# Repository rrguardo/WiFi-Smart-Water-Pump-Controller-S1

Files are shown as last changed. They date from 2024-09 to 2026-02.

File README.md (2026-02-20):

# WiFi Smart Water Pump Controller S1

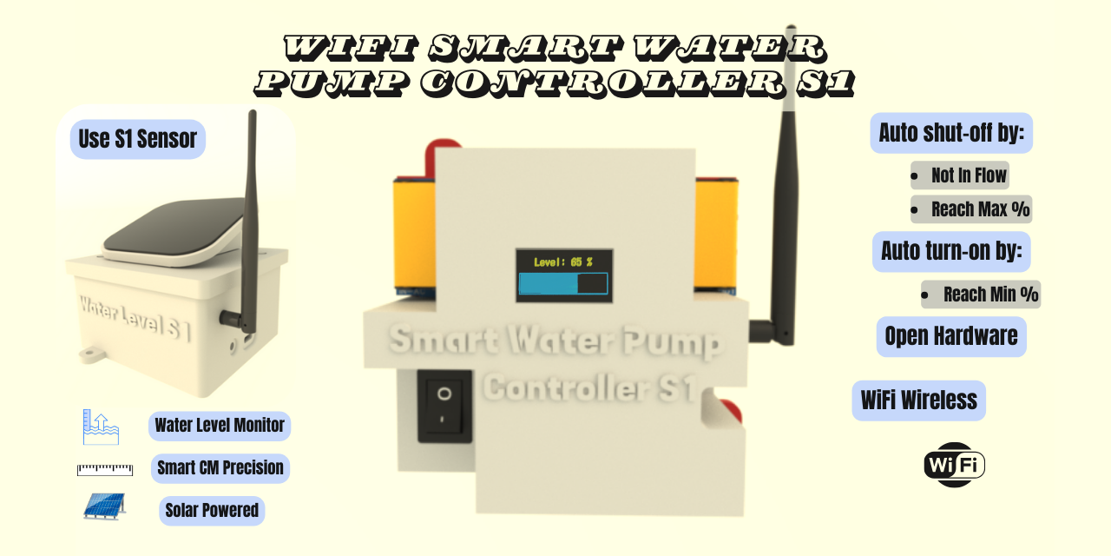
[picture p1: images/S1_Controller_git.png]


## Introduction

The [WiFi Smart Water Pump Controller S1](https://waterlevel.pro/products/WiFi-Smart-Water-Pump-Controller-S1)  is an innovative device 
engineered to provide seamless control of water pumps through WiFi connectivity. 
Designed to integrate effortlessly with the [WiFi Water Level S1](https://github.com/rrguardo/WiFi-Water-Level-S1), this controller 
offers a comprehensive solution for managing water levels and automating pump operations. 
Whether for residential, agricultural, or industrial applications, it enables efficient and remote 
management of water systems.

The system is cloud-connected, requiring an internet connection, 
and is designed for reliable, continuous operation. For more details,
refer to the [full features page](https://waterlevel.pro/products/WiFi-Smart-Water-Pump-Controller-S1).

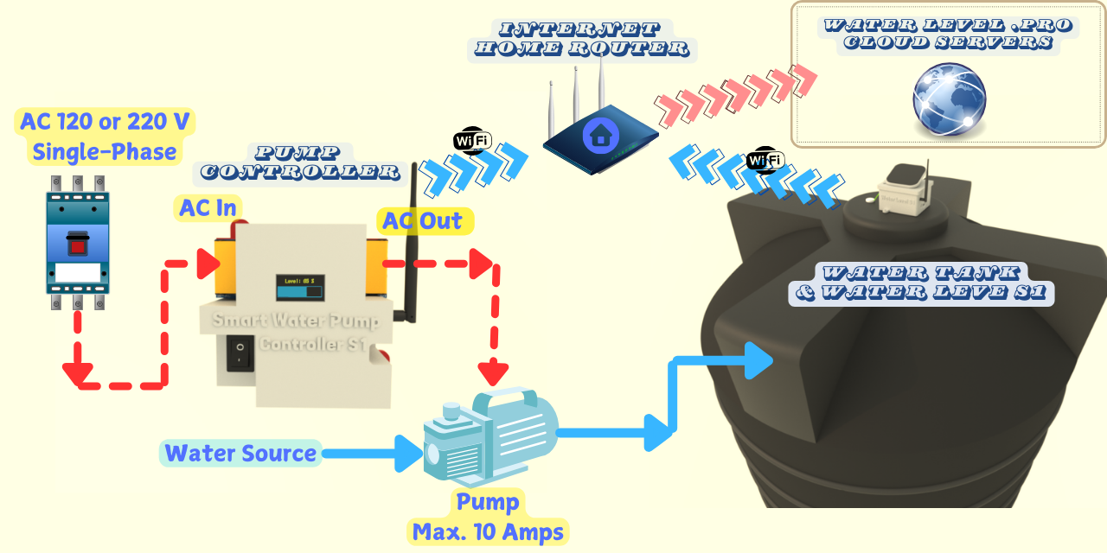
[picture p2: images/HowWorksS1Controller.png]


## Server-Side Platform

The server-side project used by this controller is available at:
[WaterLevel.Pro server-side repository](https://github.com/rrguardo/WaterLevel.Pro)

WiFi Smart Water Pump Controller S1

Related server-side features include device-to-cloud communication endpoints,
remote pump control actions, water-level telemetry handling, alert/event workflows,
and account-based multi-device management for monitoring and automation.

The project is open source and open hardware, licensed under GPLv3. All hardware, software, and
3D printable components were designed from scratch by me, **Raul Rodriguez Guardo**, and are released 
under the GPLv3 license, allowing for free use and modification.

<div align="center">
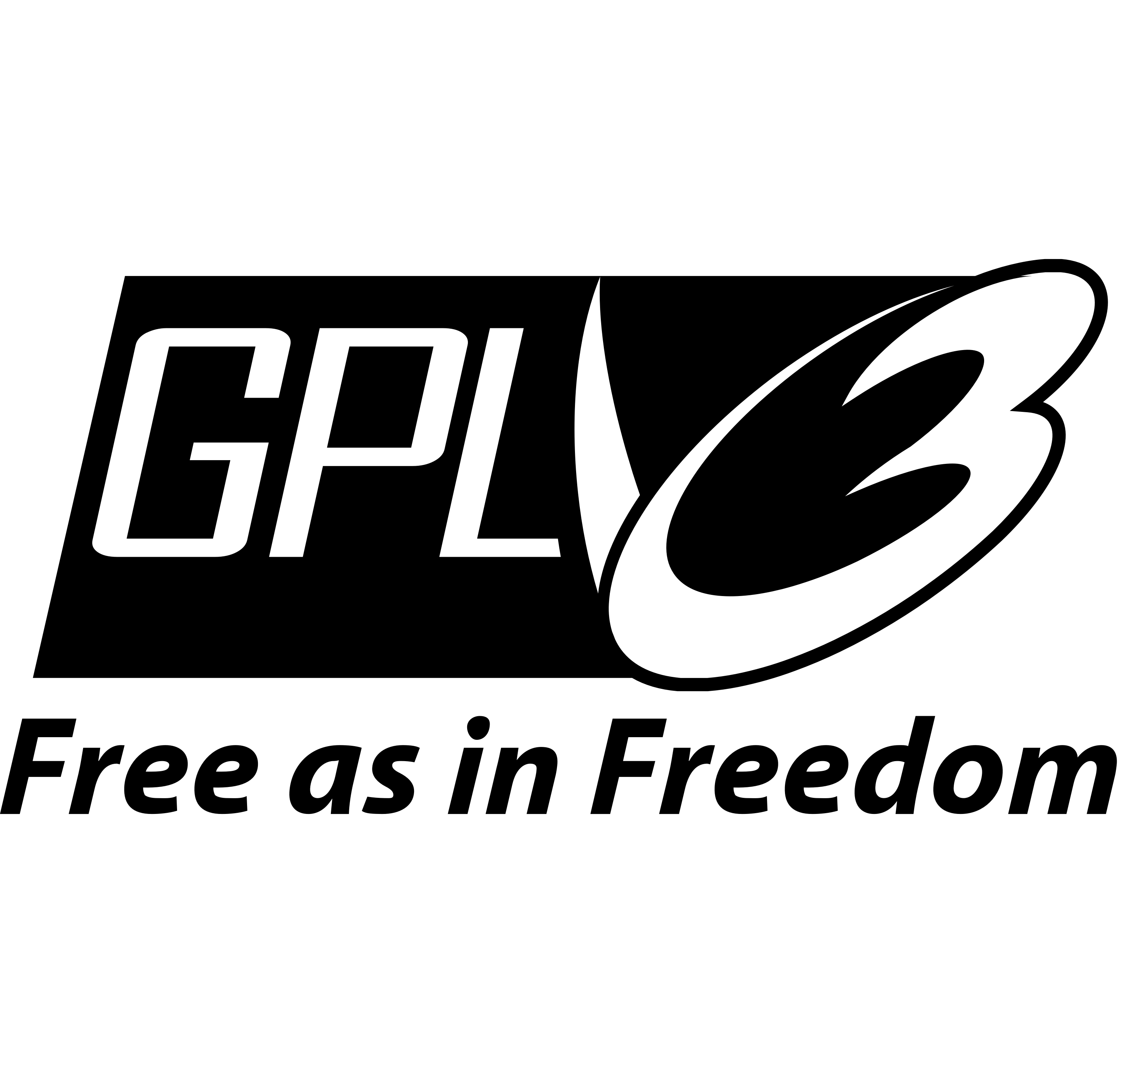
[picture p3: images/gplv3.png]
Imagen 2
  
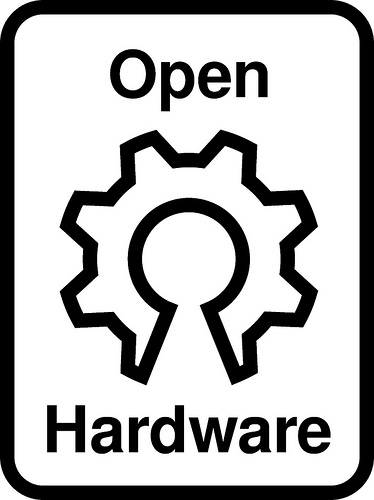
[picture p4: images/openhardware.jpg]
Imagen 1
  
</div>

---

## DIY Guide

For a detailed guide on how to build this project, check out the full tutorial at [Instructables](https://www.instructables.com/DIY-WiFi-Smart-Water-Pump-Controller-S1-Build-Your/).

---

## Hardware part at OSHWLab

[SmartSwitch C3 Module](https://oshwlab.com/rrguardo83/automatic-water-pump-for-s1)

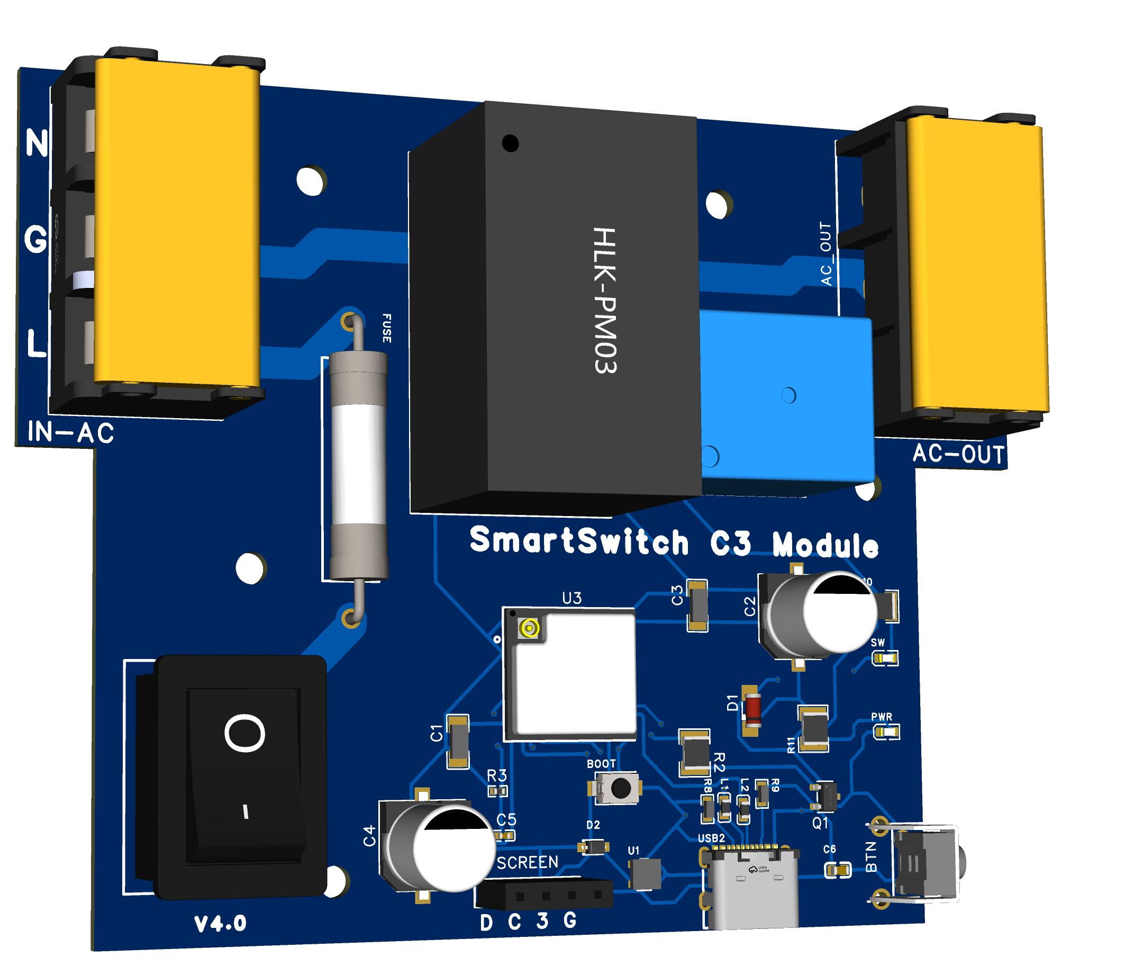
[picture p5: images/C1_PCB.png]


### Where buy the PCB board?
[At OSHWLab project, opening the EasyEDA](https://oshwlab.com/rrguardo83/automatic-water-pump-for-s1) 
editor can in few click buy the entire board with all the PCB components including the components assembly, 
directly from **JLCPCB** and **LCSC** services.

### PCB Component Roles Diagram

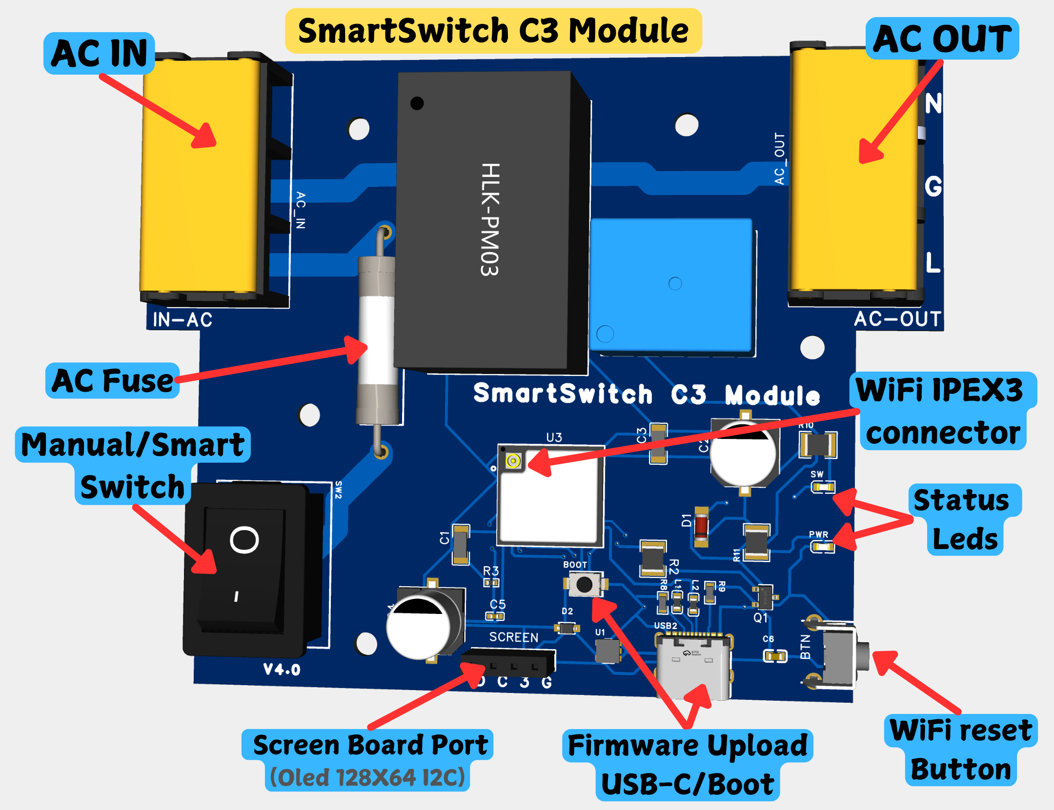
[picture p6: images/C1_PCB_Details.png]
S1 PCB Features


---

## Microcontroller Software

[ArduinoIDE INO File](MicrocontrollerCode.ino)

This devide use ESP32-C3 microcontroller can use Arduino IDE to flash/upload microcontroller code, using **ESP32C3 Dev Module** as board.

[Download Latest Firmware Builds Here](SmartPumpControllerS1/firmwares/)

---
## FreeCad 3D printable case components

[3D printable case components](3dcase)

For more details about important 3d printing recommendations 
 [read this tips](3dcase/3DPrintReadme.md).

Smart Water Pump Controller S1

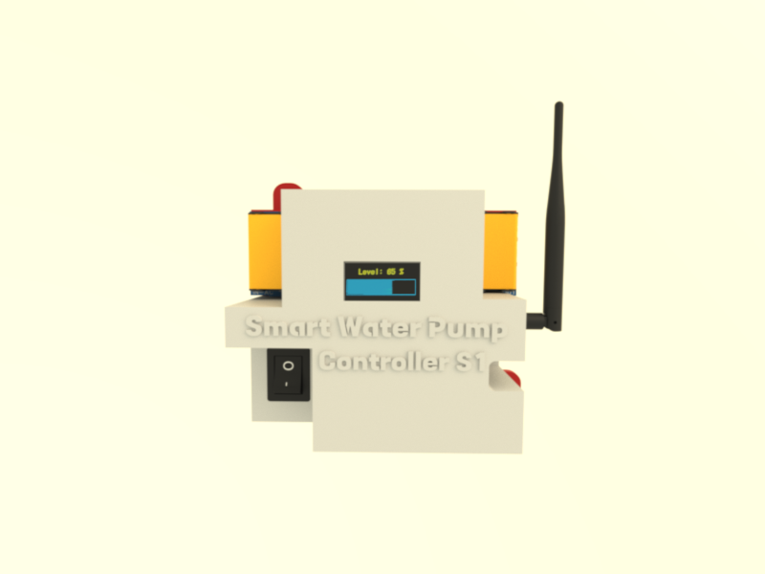
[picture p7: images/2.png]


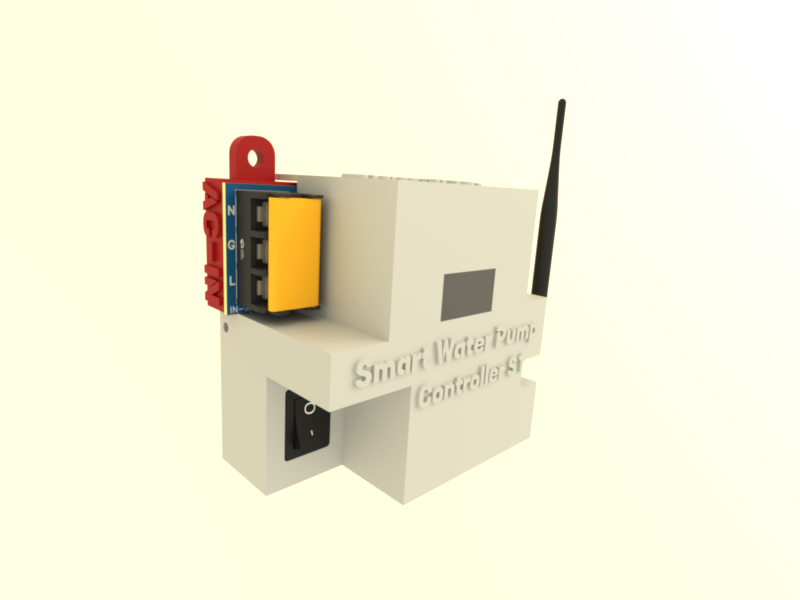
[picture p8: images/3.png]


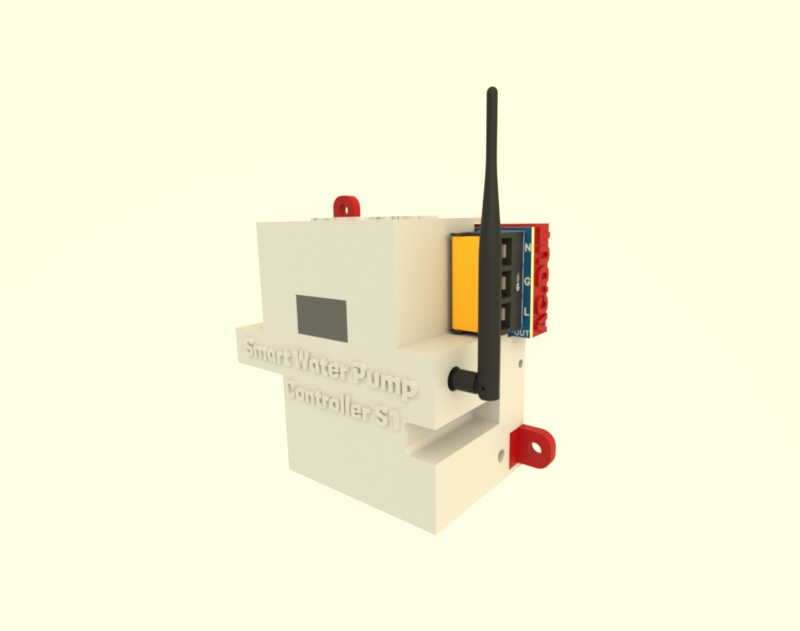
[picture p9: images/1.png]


---

### No 3D Printer? No Problem! Easily Print Parts Using Online 3D Printing Service

| **3D Print Provider** | **Recommended Materials for Outdoors** | **Approximate Price** | **Print Quality** | **Delivery Options** | **Comments** |
|---|---|---|---|---|---|
| **JLCPCB (JLC3DP)** | Nylon (PA12) | Low to Medium | High for resin and MJF | International, economical | Great value for money, lacks PETG or ASA options |
| **Shapeways** | Nylon, Stainless Steel, Aluminum | Medium to High | Very high, detailed | International, fast | Ideal for high-detail projects and outdoor durable parts |
| **Sculpteo** | Nylon (PA12), Aluminum, Carbon-Reinforced Nylon | Medium | High | International, fast options | Wide range of materials, good for durable prototypes |
| **3D Hubs** | PETG, ABS, Nylon, Carbon Fiber-Reinforced Materials | Medium | High, varies by local provider | International, varies | Global network, quality and delivery times vary by provider|
| **Craftcloud** | PETG, Nylon, ASA, Carbon Fiber-Reinforced Materials | Medium | High, varies by provider | International, varies | Service aggregator, good price comparison across providers |
| **Materialise** | Nylon (PA12), Carbon-Reinforced Nylon, Metals | High | Very high, industrial focus | International, fast | Focus on industrial and professional applications |
| **Xometry** | Nylon, ABS, PETG, Aluminum, Carbon-Reinforced Nylon | Medium to High | Very high, professional focus | International, fast | Ideal for custom manufacturing and durable industrial parts|

Choose durable materials like **PETG**, and set **infill at 60%** or higher for added strength. Just upload the 3D files and get everything printed and shipped to you!

---
## User Installation And Usage Manual

The [installation manual](https://waterlevel.pro/manuals/WiFi-Smart-Water-Pump-Controller-S1) provides 
detailed instructions on setting up the **WiFi Smart Water Pump Controller S1**. 
Be sure to [read all instructions](https://waterlevel.pro/manuals/WiFi-Smart-Water-Pump-Controller-S1) 
carefully before proceeding with the installation to ensure proper 
setup and functionality.

[WiFi Smart Water Pump Controller S1 , User Manual](https://waterlevel.pro/manuals/WiFi-Smart-Water-Pump-Controller-S1)

---

## What parts are opensource?

* All the hardware part
  * Electronics part: PCB, schematic.
  * Printable 3D Case
* Firmware software

The server side implementation used by this device is maintained in a separate repository:
[https://github.com/rrguardo/WaterLevel.Pro](https://github.com/rrguardo/WaterLevel.Pro).
This firmware/hardware repository does not include the server-side source code directly.

---

## Important Disclaimer

> **Disclaimer:**  
This open-source electronics project/device is provided strictly for experimental, educational, and developmental purposes. It is offered "as is," without any warranties, express or implied. This includes, but is not limited to, implied warranties of merchantability, fitness for a particular purpose, or non-infringement.

### By using this device, you acknowledge and accept that:

- You assume all risks associated with its use, including but not limited to potential damage to property, personal injury, or any other unintended consequences.
- This device is not certified for commercial, industrial, or safety-critical applications. It is intended solely for developers, hobbyists, and other users with appropriate technical expertise.
- The creators and distributors of this project are not liable for any damages, losses, or inconveniences resulting from its use, modification, or integration into other systems.

Users are solely responsible for ensuring that the use of this device complies with local laws, regulations, and safety standards in their region.

---

<div align="center">
  <h5>Designed in the Dominican Republic 2024-2025</h5>
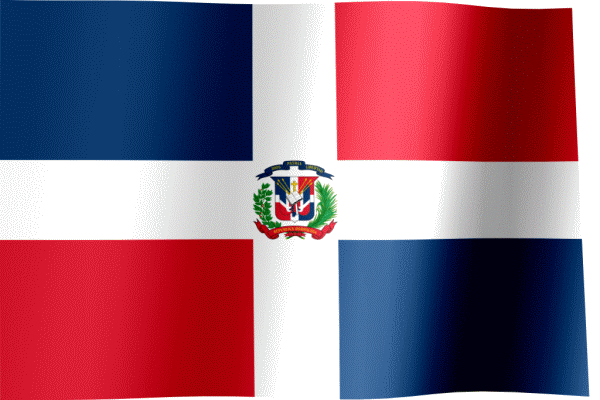
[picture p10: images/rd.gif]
RD
  
</div>

---

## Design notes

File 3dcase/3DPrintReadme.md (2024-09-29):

# Recommendations for Printing an Outdoor Case

To ensure that a case designed for outdoor use is durable and resistant to environmental conditions, follow these guidelines for various types of 3D printers and filaments:

## FDM Printers with PETG

**PETG** is a great choice for outdoor applications due to its resistance to UV light and moisture. Follow these settings for optimal results:

### Temperature Settings
- **For Brass Nozzle**: Use a nozzle temperature of 250°C.
- **For Steel Nozzle**: Use a nozzle temperature of 260°C.
- Set the bed temperature to 70°C to 80°C to ensure proper adhesion.

### Layer Height
- Use a smaller layer height (e.g., 0.2mm) to ensure finer details and better strength.

### Infill Density
- Set the infill density to at least 50% to provide adequate strength and durability. For high-impact areas, consider increasing to 100%.

### Wall Thickness
- Increase wall thickness (e.g., 4 to 6 walls) to enhance the structural integrity of the case and improve resistance to physical impacts.

### Cooling
- Use minimal cooling to prevent warping and ensure strong layer bonding.

### Annealing
- Consider annealing the printed case to improve strength and durability. This process can enhance PETG’s resistance to environmental factors.

## Other Types of Printers and Filaments

### SLA/DLP Printers
- **Resin**: Use UV-resistant resin for better durability against sunlight and weather conditions.
- **Settings**: Follow manufacturer recommendations for curing times and temperatures to ensure optimal print quality and resistance.

### SLS Printers
- **Nylon (PA)**: Use nylon, as it offers good resistance to UV light and moisture. It is also known for its toughness.
- **Settings**: Follow specific printer and material guidelines for temperature and print settings.

### High-Performance Materials
- **ABS**: For a more traditional choice, ABS can be used if UV resistance is not a primary concern, but it may require additional post-processing for outdoor use.
- **Polycarbonate (PC)**: This material provides excellent impact resistance and can withstand extreme temperatures, making it suitable for harsh environments.

## Sealing and Assembly Tips

- **Silicone Adhesive**: Use silicone adhesive or a glue gun with silicone sticks to seal and protect the case. Apply silicone to seal connectors, buttons, cables, and other openings to prevent moisture ingress and improve overall durability.
- **Sealing Joints**: Ensure that all seams and joints are properly sealed with silicone to protect against water and humidity.

## General Tips
- **Post-Processing**: Consider applying a UV-resistant coating or paint to further enhance protection against environmental elements.
- **Sealing**: Ensure that all seams and joints are properly sealed to prevent water ingress.

By following these recommendations, you can create a durable and resilient case suitable for outdoor environments.

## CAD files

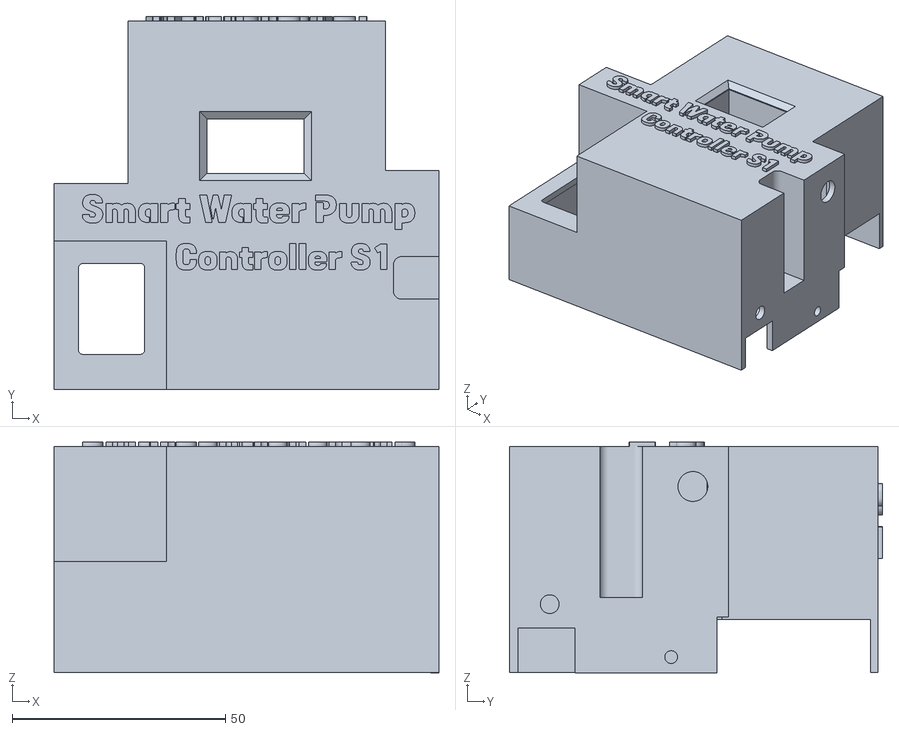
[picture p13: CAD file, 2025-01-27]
3dcase/Lid.stl
90.3 x 87.5 x 54.1

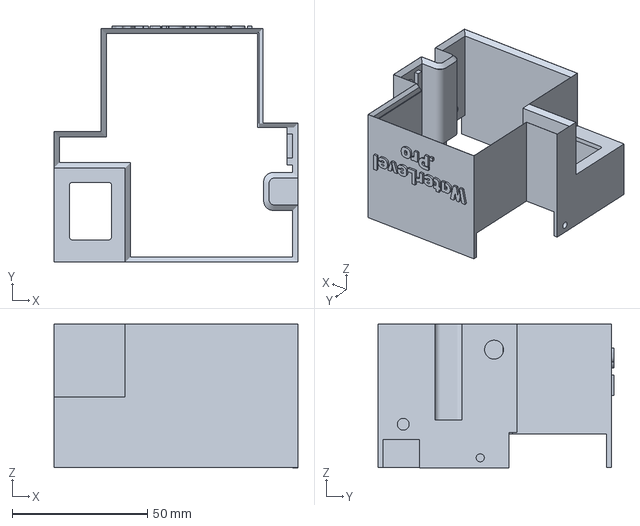
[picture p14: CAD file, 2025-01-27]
3dcase/SplitVersion/LidBottom.3mf
90.2 x 87.4 x 53.1 mm

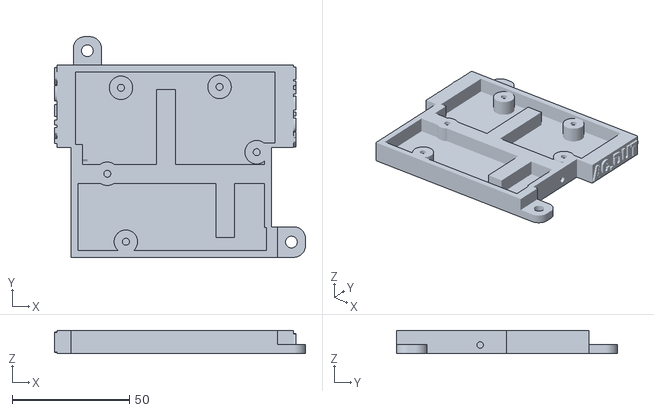
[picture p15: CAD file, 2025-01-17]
3dcase/Base.stl
106.9 x 93.9 x 10.0

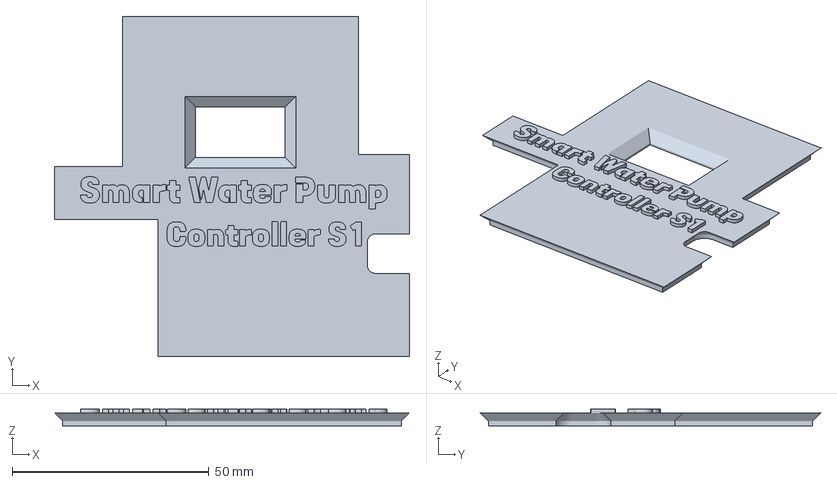
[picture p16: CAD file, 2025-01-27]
3dcase/SplitVersion/LidTop.3mf
90.2 x 86.4 x 4.30 mm

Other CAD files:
3dcase/SplitVersion/LidBottom.stl
3dcase/SplitVersion/LidTop.stl

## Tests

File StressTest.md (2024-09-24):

## AC Device Stress Test

### Introduction: 
A stress test was conducted on the AC device at 120V, 60 Hz, with a constant load of 1200W (10 A) for 3 minutes.  Using a PCB with a outer copper weight of only 1 oz.

### Results: 
The device operated without issues, showing no visible burns or melting. However, the AC connectors and components reached very high temperatures, estimated around 90 °C.

Conclusions: While the device functioned correctly under limit load, the high temperature of the connectors is concerning and could affect its longevity. It is recommended to improve ventilation and consider using heat-resistant connectors for prolonged operations. 
Additionally, using a PCB with a copper weight of 2 oz or more is advised to enhance thermal management.

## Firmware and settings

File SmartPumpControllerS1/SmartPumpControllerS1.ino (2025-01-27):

// ongoing project, current progress

/*
 * This file is part of WiFi Smart Water Pump Controller S1 project.
 *
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
 */

// IDE and Board
// Board: ESP32-C3-MINI-1U-H4 
// Arduino Framework version: 2.3.4
// Arduino Board Module: ESP32C3 Dev Module
// Board Manager URL: https://arduino.esp8266.com/stable/package_esp8266com_index.json 

// Libraries used:
// WiFiManager by tzapu version: 2.0.16-rc.2 
// U8g2 by oliver version: 2.35.30 
// Time by Michael Margolis version: 1.6.1


#include <Arduino.h>
#include <U8g2lib.h>

#include <TimeLib.h>


#include <WiFiManager.h>
#include <HTTPClient.h>
//#include "certs.h"

#include <nvs_flash.h>
#include <String.h>

#include <Update.h>
#include <math.h>


#define RELAY_PIN_1 0
#define EMAIL_MAX_LENGTH 128
#define DEBUG  // Comment this line to disable serial prints
#define BLIND_MARGIN_EXTRA 2 // extra margin added

// DEV MODE allow app update remote
const bool DEV_MODE = false; // used for ON/OFF live-updates and other other safety instructions for easy development
const bool LIVE_UPDATE = true; // used for ON/OFF live-updates and other other safety instructions for easy development

const char* firmwareUrl = "https://waterlevel.pro/static/fw";
int FIRMW_VER = 19;

// Pin del botón wifi-setup/reset
const int pinBoton = 1;

// Replace this with the URL you want to send the GET request to
const char* host_url = "https://api.waterlevel.pro/relay-update";

const char* host_link_url = "https://api.waterlevel.pro/link";

char api_key[128] = "-";  //  PRIVATE KEY HERE // "-" none-null-api-key
// use value "-" for automatic api key setup
// or manually generate and use new key in developer zone at https://waterlevel.pro/settings   https://waterlevel.pro/add_relay


const char* WIFI_NAME = "WaterLevelProSetup";
const char* WIFI_PASSW = "1122334455";
char email[EMAIL_MAX_LENGTH] = "-";  // Variable to store email

WiFiManager wm;
// Set custom email parameter
WiFiManagerParameter custom_email("email", "Enter Email", email, EMAIL_MAX_LENGTH, "type='email' required placeholder='example@example.com'");


nvs_handle_t my_nvs_handle;
unsigned long tiempoArranque;

// relay status 0-off / 1-on
int RelayStatus = 0;

int ALGO = 0; // 0 none, 1 (llenar a 90% al ancanzar 30%)
int SAFE_MODE = 1;
int START_LEVEL = 0; // in %
int END_LEVEL = 0; // in %
int AUTO_OFF = 0;
int AUTO_ON = 0;
int ACTION = 0; //0 none, -1 off, 1 on
int IDLE_CONNECTION_SECS = 0; // calc. based on sensor pool-time
int MIN_FLOW_MM_X_MIN = 0;
int BLIND_DISTANCE = 22;
String HOURS_OFF = "-";
int WIFI_POOL_TIME = 10000; // wifi usage pool time in mili-seconds

int Sensor5History[10] = {-1, -1, -1, -1, -1, -1, -1, -1, -1, -1};


int sens_percent = 0; // filled percent
int sens_event_time = 0;
int sens_current_time = 0;

int sensor_last_distance = 0;
int sensor_last_pool_time = 0;
int sens_event_last_time = 0;

unsigned long LAST_DATA_TIME = 0;
unsigned long IDLE_FLOW_EVENT_TIME = 0;
unsigned long relay_on_start_time = 0;
bool IS_WAITING = false;

// FLOW IDDLE VARIABLES
const int IDLE_RECOVERY_SEC = 60*60*3; // IDLE RECOVERY TIME before try again after low flow detected (1 hours)
int32_t rssi = 0;

String FLOW_EVENTS = "";

int Reset_BTN_Count = 0;
enum ConfigStatus {
  WIFI_SETUP,
  WIFI
};

ConfigStatus CurrentStatus = WIFI_SETUP;

enum EventLogs {
  NO_EVENT,
  BLIND_AREA,
  BLIND_AREA_DANGER,
  NOT_FLOW,
  OFFLINE,
  IDDLE_SENSOR,
  END_LEVEL_EVENT,
  START_LEVEL_EVENT,
  SETUP_WIFI,
  BOOT,
  PUMP_ON,
  PUMP_OFF,
  DATA_POST_FAIL,
  BTN_PRESS,
  SENSOR_FAULT
};

EventLogs EventsArray[5] = {NO_EVENT, NO_EVENT, NO_EVENT, NO_EVENT, NO_EVENT};


U8G2_SSD1306_128X64_NONAME_F_SW_I2C u8g2(U8G2_R0, /*clock=*/9, /*data=*/8, U8X8_PIN_NONE);


void setup() {

  // Inicializamos los pines de control de los relés como salidas
  pinMode(RELAY_PIN_1, OUTPUT);
  // Desactivamos los relés al inicio
  digitalWrite(RELAY_PIN_1, LOW);


  tiempoArranque = millis();
  // Configuramos el pin del botón como entrada
  pinMode(pinBoton, INPUT_PULLUP);
  // Asociamos la función botonPresionado() al pin del botón
  attachInterrupt(pinBoton, botonPresionado, FALLING);
  

  // Inicializamos la comunicación serial para debug (opcional)
  Serial.begin(115200);
  AddEvent(BOOT);

  u8g2.begin();

  u8g2.clearBuffer();
  u8g2.setFont(u8g2_font_7x14B_tr);
  u8g2.drawButtonUTF8(64, 10, U8G2_BTN_HCENTER, 0,  2,  2, "Starting ..." );
  u8g2.sendBuffer();

  // Iniciar la memoria flash
  esp_err_t err = nvs_flash_init();

  if (err == ESP_ERR_NVS_NO_FREE_PAGES || err == ESP_ERR_NVS_NEW_VERSION_FOUND) {
      // NVS partition was truncated and needs to be erased
      // Retry nvs_flash_init
      ESP_ERROR_CHECK(nvs_flash_erase());
      err = nvs_flash_init();
  }
  ESP_ERROR_CHECK( err );
  err = nvs_open("storage", NVS_READWRITE, &my_nvs_handle);
  if (err != ESP_OK) {
        Serial.println("Error opening nvs handler");
  } else {
      Serial.println("Done opening nvs handler");
  }

  // Add parameter to WiFiManager
  wm.addParameter(&custom_email);
  // Set config save callback
  wm.setSaveConfigCallback(saveConfigCallback);

  RelayStatus = 0;
  ALGO = 0;
  SAFE_MODE = 0;
  START_LEVEL = 0;
  END_LEVEL = 0;
  AUTO_OFF = 0;
  AUTO_ON = 0;
  ACTION = 0;
  MIN_FLOW_MM_X_MIN = 0;
  IDLE_FLOW_EVENT_TIME = 0;
  Reset_BTN_Count = 0;
  WIFI_POOL_TIME = 10000;

  IS_WAITING = false;

  LAST_DATA_TIME = millis();
  IDLE_CONNECTION_SECS = 0;

  load_local_settings();
  load_private_key();

  if(CurrentStatus == WIFI_SETUP){
    u8g2.clearBuffer();
    u8g2.setFont(u8g2_font_7x14B_tr);
    u8g2.drawButtonUTF8(64, 10, U8G2_BTN_HCENTER, 0,  2,  2, "WiFi Reset/Setup" );
    u8g2.sendBuffer();

    AddEvent(SETUP_WIFI);
    SetupResetWifi();
    
  }else{
    ConnectWifi();
  }
  
}


void saveConfigCallback() {
  Serial.println("Enter saveConfigCallback");
  // Placeholder for additional code to handle saving to persistent storage, if needed

  // Guardar el email en EEPROM
  const char *newEmail = custom_email.getValue();
  strncpy(email, newEmail, sizeof(email) - 1); // Copiar el nuevo valor
  email[sizeof(email) - 1] = '\0'; // Asegurar que termina con '\0'


  if(myStrlen(email) >= 7 ){

    #ifdef DEBUG
      Serial.print("Email to linked: ");
      Serial.println(email);
    #else
       delay(5);
    #endif
  }else{
    Serial.print("Invalid email: ");
    Serial.println(email);
    strcpy(email, "-");
  }

}
  

int myStrlen(const char* str) {
  int len = 0;
  while (*str != '\0') {
    len++;
    str++;
  }
  return len;
}

void non_lock_delay(unsigned long mili_seconds) {
  static unsigned long previousMillis = 0;
  static bool isWaiting = false;

  unsigned long currentMillis = millis();

  // Inicio de espera
  if (!isWaiting) {
    previousMillis = currentMillis;
    isWaiting = true;
  }

  while (isWaiting) {
    currentMillis = millis();
    
    // Verificar si el tiempo ha pasado
    if (currentMillis - previousMillis >= mili_seconds) {
      isWaiting = false; // Reiniciar la espera

    }

    // Permitir que el sistema operativo maneje tareas críticas
    delay(1); // Mantener el sistema operativo funcionando mientras se espera
  }
}


void load_private_key(){

  size_t required_size = 0;
  nvs_get_str(my_nvs_handle, "PrivateKey", NULL, &required_size);
  if (required_size != 0 and required_size > 10) {
    char* tmp_key = (char*)malloc(required_size);
    nvs_get_str(my_nvs_handle, "PrivateKey", tmp_key, &required_size);
    strcpy(api_key, tmp_key);  
    free(tmp_key);
    
    Serial.print("Private Key loaded from memory: ");
    Serial.println(api_key);

  }else if(strcmp(api_key, "-") != 0){
    nvs_set_str(my_nvs_handle, "PrivateKey", api_key);
    nvs_commit(my_nvs_handle);

    Serial.print("Private Key loaded from code: ");
    Serial.println(api_key);
  }

  if(myStrlen(api_key) < 10 && CurrentStatus != WIFI_SETUP){
    Serial.print("ERROR: Short API KEY: ");
    Serial.println(api_key);

    u8g2.clearBuffer();
    u8g2.setFont(u8g2_font_7x14B_tr);
    u8g2.drawButtonUTF8(64, 10, U8G2_BTN_HCENTER, 0,  2,  2, "Invalid Key!" );
    u8g2.sendBuffer();
    sleep(7);

    esp_system_abort("restart_after_wakeup");
  }

  
}


void loop() {

  //restart each 24 hours, when relay is OFF
  if(millis() > 86400000 && RelayStatus == 0){
    GetRemoteSettings();
    delay(5);
    esp_system_abort("restart_after_wakeup");
  }

  u8g2.clearBuffer();
  u8g2.setFont(u8g2_font_7x14B_tr);

  if(!DEV_MODE && millis() <= 60000){
    Serial.println("Waiting 1 min. after start 4 safe-try");

    u8g2.setFont(u8g2_font_helvR08_tr);
    u8g2.drawButtonUTF8(62, 30, U8G2_BTN_HCENTER|U8G2_BTN_BW2, 34,  2,  2, "Waiting 1 min." );

    u8g2.sendBuffer();

    non_lock_delay(10000); // Esperamos 10 segundos
    return;
  }

  GetRemoteSettings();

  char textWithInt2[100]; 
  sprintf(textWithInt2, "Level: %d %%", sens_percent);
  u8g2.drawButtonUTF8(64, 10, U8G2_BTN_HCENTER, 0,  2,  2, textWithInt2);

  drawLevel(sens_percent);
  
  if(IDLE_CONNECTION_SECS != 0){
    if(sens_current_time - sens_event_time > IDLE_CONNECTION_SECS){
        AddEvent(IDDLE_SENSOR);
        u8g2.clearBuffer();
        u8g2.setFont(u8g2_font_7x14B_tr);
        u8g2.drawButtonUTF8(64, 10, U8G2_BTN_HCENTER|U8G2_BTN_BW2, 34,  2,  2, "WARNING!" );
        u8g2.drawButtonUTF8(64, 35, U8G2_BTN_HCENTER|U8G2_BTN_BW2, 34,  2,  2, "IDLE SENSOR!" );
    }
  }

  if(ACTION == 1){
    ACTION = 0;
    RelayOn();

    IS_WAITING = false;
    IDLE_FLOW_EVENT_TIME = 0;
  }

  if(ACTION == -1){
    ACTION = 0;
    RelayOff();
  }

  if(SAFE_MODE == 1 && checkConsistency(Sensor5History, 10, 20) && sensor_last_distance <= (BLIND_DISTANCE - BLIND_MARGIN_EXTRA)){
    Serial.println("Danger blind distance detected");
    AddEvent(BLIND_AREA_DANGER);
    if(AUTO_OFF){
      RelayOff();

      u8g2.clearBuffer();
      u8g2.setFont(u8g2_font_7x14B_tr);
      u8g2.drawButtonUTF8(64, 10, U8G2_BTN_HCENTER|U8G2_BTN_BW2, 34,  2,  2, "AUTO OFF!" );
      u8g2.drawButtonUTF8(64, 35, U8G2_BTN_HCENTER|U8G2_BTN_BW2, 34,  2,  2, "Smart Mode OFF!" );

      non_lock_delay(20000); // Esperamos 20 segundos
    }
  }

  if(SAFE_MODE == 1 && Sensor5History[8] == 0 && Sensor5History[9] == 0){
    Serial.println("Danger blind distance or sensor fail detected");
    AddEvent(BLIND_AREA_DANGER);
    AddEvent(SENSOR_FAULT);
    if(AUTO_OFF){
      RelayOff();

      u8g2.clearBuffer();
      u8g2.setFont(u8g2_font_7x14B_tr);
      u8g2.drawButtonUTF8(64, 10, U8G2_BTN_HCENTER|U8G2_BTN_BW2, 34,  2,  2, "AUTO OFF!" );
      u8g2.drawButtonUTF8(64, 35, U8G2_BTN_HCENTER|U8G2_BTN_BW2, 34,  2,  2, "Smart Mode OFF!" );

      non_lock_delay(20000); // Esperamos 20 segundos
    }
  }

  if(AUTO_OFF > 0 && sensor_last_distance > 0 && sensor_last_distance <= BLIND_DISTANCE){
    AddEvent(BLIND_AREA);
    Serial.println("Top blind distance detected");
    RelayOff();

    u8g2.clearBuffer();
    u8g2.setFont(u8g2_font_7x14B_tr);
    u8g2.drawButtonUTF8(64, 10, U8G2_BTN_HCENTER|U8G2_BTN_BW2, 34,  2,  2, "AUTO OFF!" );
    u8g2.drawButtonUTF8(64, 35, U8G2_BTN_HCENTER|U8G2_BTN_BW2, 34,  2,  2, "FULL" );

    non_lock_delay(20000); // Esperamos 20 segundos
  }

  if(AUTO_OFF > 0 && IDLE_CONNECTION_SECS != 0 &&  sens_current_time > 0 && sens_event_time > 0 && sens_current_time - sens_event_time > IDLE_CONNECTION_SECS){
    AddEvent(OFFLINE);
    Serial.println("Sensor offline AUTO_OFF");
    RelayOff();

    u8g2.clearBuffer();
    u8g2.setFont(u8g2_font_7x14B_tr);
    u8g2.drawButtonUTF8(64, 10, U8G2_BTN_HCENTER|U8G2_BTN_BW2, 34,  2,  2, "AUTO OFF!" );
    u8g2.drawButtonUTF8(64, 35, U8G2_BTN_HCENTER|U8G2_BTN_BW2, 34,  2,  2, "SENSOR OFFLINE" );

    non_lock_delay(20000); // Esperamos 20 segundos
  }

  if(ALGO == 1){
    DoAlgo1();
  }
  u8g2.sendBuffer();
  non_lock_delay(WIFI_POOL_TIME); // Esperamos 10 segundos
}


void drawLevel(int percentage) {
  int barWidth = map(percentage, 0, 100, 0, u8g2.getWidth() - 11);  // Restar 20 para dejar espacio alrededor
  int barHeight = u8g2.getHeight();  // 1/4 de la altura de la pantalla
  int frameThickness = 1;  // Grosor del marco

  // Dibujar el contorno del indicador de batería
  u8g2.drawFrame(5, 18, u8g2.getWidth() - 10, u8g2.getHeight() - 35);

  // Dibujar el área de nivel de batería
  u8g2.drawBox(7, 20, barWidth, u8g2.getHeight() - 39);

}

bool checkConsistency(const int arr[], int size, int threshold) {
  // Check if last 2 sensor values have sense (>=0 and diff < threshold)

    Serial.println("checkConsistency");
    PrintHistory();
    // Check if there are at least two elements in the array
    if (size < 2) {
        return false; // Not enough elements to compare
    }

    // Get the last two values and calculate their absolute difference
    int lastValue = arr[size - 1];
    int secondLastValue = arr[size - 2];
    if(lastValue < 0 ||  secondLastValue < 0){
      return false; // not data yet
    }
    int difference = abs(lastValue - secondLastValue);

    // Return true if the difference is within the threshold
    return difference <= threshold;
}


int GetHour(int utcTimestamp, int gmt_number){
  // Apply the GMT-4 offset (4 hours behind UTC)
  time_t gmtMinus4Timestamp = (time_t)utcTimestamp - (gmt_number * 3600); // Subtract 4

  // Convert GMT-4 timestamp to a tm struct
  tmElements_t tm;
  breakTime(gmtMinus4Timestamp, tm);

  Serial.print("Hour: ");
  Serial.println(tm.Hour);

  return tm.Hour;
}


void PrintHistory(){
  #ifdef DEBUG
    Serial.println("======================");
      Serial.println("Sensor5History: ");

      for (int i = 0; i <= 9; i++) {
        Serial.println(Sensor5History[i]);
      }
    Serial.println("======================");
  #endif
}

// ALGO #1 - try auto-start if capacity is under 30%, stop at 90%
// use simple iddle flow detection based in basic check
void DoAlgo1(){

  /*
  RelayStatus = 0;
  ALGO = 0;
  START_LEVEL = 0;
  END_LEVEL = 0;
  AUTO_OFF = 0;
  AUTO_ON = 0;
  ACTION = 0;

  MIN_FLOW_MM_X_MIN
  sensor_last_distance
  sensor_last_pool_time 
  */
 
  if(RelayStatus == 1 && IDLE_CONNECTION_SECS > 0 && (millis() - LAST_DATA_TIME >= IDLE_CONNECTION_SECS*1000)){
    AddEvent(OFFLINE);
    Serial.println("Long iddle connection time");
    RelayStatus = 0;
    sens_current_time = 0;
    sens_event_time = 0;
    RelayOff();
    return;
  }

  // Stop ALGO after 10 PM and before 9 AM
  if(sens_current_time > 0){
      int gtm_4_hour = GetHour(sens_current_time, 4);
      if(isHourInList(HOURS_OFF, gtm_4_hour)){
        Serial.println("Off hours detected");

        u8g2.sendBuffer();
        non_lock_delay(10000);
        u8g2.clearBuffer();
        u8g2.setFont(u8g2_font_7x14B_tr);
        u8g2.drawButtonUTF8(64, 10, U8G2_BTN_HCENTER|U8G2_BTN_BW2, 34,  2,  2, "WARNING!" );
        u8g2.drawButtonUTF8(64, 35, U8G2_BTN_HCENTER|U8G2_BTN_BW2, 34,  2,  2, "Disabled Hours!" );
        u8g2.sendBuffer();
        non_lock_delay(5000);

        RelayOff();
        return;
      }
  }
  
  if(sens_current_time == 0 || sens_event_time == 0 ){
      Serial.println("Not sensor data detected!");
      sens_current_time = 0;
      sens_event_time = 0;
      return;
  }

  if(IDLE_CONNECTION_SECS != 0){
    if(sens_current_time - sens_event_time > IDLE_CONNECTION_SECS){
      AddEvent(IDDLE_SENSOR);
      Serial.println("Idle sensor detected!");
      sens_current_time = 0;
      sens_event_time = 0;
      RelayOff();
      return;
    }
  }

  /*  
    MIN_FLOW_MM_X_MIN
    sensor_last_distance
    sensor_last_pool_time 
  */

  // case: waiting after IDDLE FLOW
  if(IS_WAITING && (IDLE_FLOW_EVENT_TIME + IDLE_RECOVERY_SEC*1000) >= millis()){
    Serial.println("Waiting 3 hours for better flow");

    u8g2.sendBuffer();
    non_lock_delay(10000);
    u8g2.clearBuffer();
    u8g2.setFont(u8g2_font_7x14B_tr);
    u8g2.drawButtonUTF8(64, 10, U8G2_BTN_HCENTER|U8G2_BTN_BW2, 34,  2,  2, "WARNING!" );
    u8g2.drawButtonUTF8(64, 35, U8G2_BTN_HCENTER|U8G2_BTN_BW2, 34,  2,  2, "Low Flow, Waiting!" );
    u8g2.sendBuffer();
    non_lock_delay(5000);

    return;
  }else if(IS_WAITING){
    Serial.println("Waiting done!");
    IS_WAITING = false;
    IDLE_FLOW_EVENT_TIME = 0;
    RelayOn();
  }

  // case: IDDLE FLOW 
  if(RelayStatus == 1 && MIN_FLOW_MM_X_MIN > 0 && sensor_last_distance > 0 && sensor_last_pool_time > 0){

    unsigned long runing_time = millis() - relay_on_start_time;
    if(MIN_FLOW_MM_X_MIN*60000 < runing_time){

      PrintHistory();

      if(!FlowHistoryGrow(Sensor5History, 10)){
        AddEvent(NOT_FLOW);
        IDLE_FLOW_EVENT_TIME = millis();
        RelayOff();
        IS_WAITING = true;
        Serial.println("Slow flow detected");
        return;
      }
    }
  }

  
  sens_current_time = 0;
  sens_event_time = 0;

  Serial.print("sens_percent: ");
  Serial.println(sens_percent);

  if(sens_percent <= START_LEVEL && RelayStatus == 0 && AUTO_ON == 1 && checkConsistency(Sensor5History, 10, 20)){
    AddEvent(START_LEVEL_EVENT);
    Serial.println("AUTO_ON ON");
    RelayOn();
  }

  if(sens_percent >= END_LEVEL && RelayStatus == 1 && AUTO_OFF == 1 && checkConsistency(Sensor5History, 10, 20)){
    AddEvent(END_LEVEL_EVENT);
    Serial.println("AUTO_OFF OFF");
    RelayOff();
  }
}


bool FlowHistoryGrow(const int arr[], int size) {

  for (int i = 1; i < size - 1; i++) { // Iterate from the second to the second-last element
        bool hasGreaterLeft = false;  // To check if there's a greater number on the left

        // Check for a greater number on the left
        for (int j = 0; j < i; j++) {
            if (arr[j] > arr[i] && arr[i] >= 0) {
                hasGreaterLeft = true;
                break;
            }
        }

        // If both conditions are met, return true
        if (hasGreaterLeft) {
            return true;
        }
    }

    return false; // Return false if no element meets the conditions
}


void RelayOn(){
  if(RelayStatus == 0){
    AddEvent(PUMP_ON);
  }
  digitalWrite(RELAY_PIN_1, HIGH); // Activamos el primer relé
  Serial.println("Relay ON");
  RelayStatus = 1;
  Reset_BTN_Count = 0;

  IS_WAITING = false;
  IDLE_FLOW_EVENT_TIME = 0;
  relay_on_start_time = millis();

}

void RelayOff(){
  if(RelayStatus == 1){
    AddEvent(PUMP_OFF);
  }
  digitalWrite(RELAY_PIN_1, LOW); // Activamos el primer relé
  Serial.println("Relay OFF");
  RelayStatus = 0;
  ACTION = 0;
  Reset_BTN_Count = 0;
}

void load_local_settings(){

  int32_t status;
  nvs_get_i32(my_nvs_handle, "0-status", &status);

  Serial.print("Loaded Status: ");
  Serial.println(status);

  if(status >= 0 && status <= 1){
    CurrentStatus = (ConfigStatus)status;
  }else{
    Serial.println("EEPROM DEF!");
    nvs_set_i32(my_nvs_handle, "0-status", (int32_t)WIFI_SETUP);
    nvs_commit(my_nvs_handle);
    CurrentStatus = WIFI_SETUP;
  }

  Serial.print("Status Loaded = ");
  Serial.println(CurrentStatus);

}



bool ConnectWifi(){

    //WiFi.setTxPower(WIFI_POWER_8_5dBm);
    WiFi.mode(WIFI_STA); // explicitly set mode
    //WiFi.setTxPower(WIFI_POWER_8_5dBm);
    //wifi_station_connect();
    delay(5);

    wm.setConnectRetries(3);
    wm.setConnectTimeout(15);
    wm.setTimeout(15);

    std::vector<const char *> menu = {"wifi","restart","exit"};
    wm.setMenu(menu);
  
    // set configportal timeout 10 sec
    wm.setConfigPortalTimeout(15);

    if (!wm.autoConnect(WIFI_NAME, WIFI_PASSW)) {
      Serial.println("failed to connect and hit timeout");
      return false;
    }

    Serial.println("WiFi Connected!");

    rssi = WiFi.RSSI();
    Serial.print("Signal strength (RSSI): ");
    Serial.print(rssi);
    Serial.println(" dBm");


    return true;
}


void SetLocalConf(int _ALGO, int _START_LEVEL, int _END_LEVEL, int _AUTO_OFF, int _AUTO_ON, int _MIN_FLOW_MM_X_MIN, int _ACTION, int _BLIND_DISTANCE, String _HOURS_OFF, int _SAFE_MODE){

  Serial.print("SetLocalConf: _MIN_FLOW_MM_X_MIN: ");
  Serial.println(_MIN_FLOW_MM_X_MIN);

  if(_ACTION == 1 || _ACTION == -1){
    ACTION = _ACTION;
    return;
  }
  
  if(_ALGO >=0 && _ALGO <= 100){
    ALGO = _ALGO;
  }

  if(_SAFE_MODE >=0 && _SAFE_MODE <=1){
    SAFE_MODE = _SAFE_MODE;
  }

  if(_START_LEVEL >=0 && _START_LEVEL <= 800){
    START_LEVEL = _START_LEVEL;
  }

  if(_END_LEVEL >=0 && _END_LEVEL <= 800){
    END_LEVEL = _END_LEVEL;
  }

  if(_AUTO_OFF >=0 && _AUTO_OFF <= 1){
    AUTO_OFF = _AUTO_OFF;
  }

  if(_AUTO_ON >=0 && _AUTO_ON <= 1){
    AUTO_ON = _AUTO_ON;
  }

  if(_MIN_FLOW_MM_X_MIN >=0){
    MIN_FLOW_MM_X_MIN = _MIN_FLOW_MM_X_MIN;
  }

  if(_BLIND_DISTANCE >= 0){
    BLIND_DISTANCE = _BLIND_DISTANCE + BLIND_MARGIN_EXTRA;
  }

  HOURS_OFF = _HOURS_OFF;

}


String splitString(const String &dataString, int *resultArray, int arraySize) {
  // Utilizar strtok para dividir la cadena en tokens basados en el delimitador '|'
  char *token = strtok(const_cast<char*>(dataString.c_str()), "|");

  // Iterar a través de los tokens y convertirlos en enteros
  int i = 0;
  String sensor_key;
  while (token != NULL && i < arraySize) {
    // Utilizar atoi para convertir el token en un entero
    if(i == 6){
        sensor_key = String(token);
    }else{
      resultArray[i] = atoi(token);
    }
    

    // Obtener el siguiente token
    token = strtok(NULL, "|");

    // Incrementar el índice
    i++;
  }

  return sensor_key;
}


bool isHourInList(String hourList, int hour) {
  // Validate that the hour is within the allowed range
  if (hour < 0 || hour > 23) {
    return false;
  }

  // Convert the hour to a string
  String hourStr = String(hour);

  // Add commas to handle matches at the start, middle, and end of the list
  String formattedList = "," + hourList + ",";
  String formattedHour = "," + hourStr + ",";

  // Check if the formatted hour is in the formatted list
  return formattedList.indexOf(formattedHour) != -1;
}
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

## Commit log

2024-09-29 3d case models
    [Base.stl, Lid.stl]
2024-10-29 3d case update
    [Base.stl, Lid.stl]
2024-12-29 model updates
    [Base.stl, Lid.stl]
2025-01-01 Auto-link relay
2025-01-12 Donations info
    [Lid_V2.stl]
2025-01-17 small 3d case updates
    [Base.stl, Lid.stl, Lid_V2.stl]
2025-01-27 3dcase split version
    [Lid.stl, LidBottom.3mf, LidBottom.stl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]

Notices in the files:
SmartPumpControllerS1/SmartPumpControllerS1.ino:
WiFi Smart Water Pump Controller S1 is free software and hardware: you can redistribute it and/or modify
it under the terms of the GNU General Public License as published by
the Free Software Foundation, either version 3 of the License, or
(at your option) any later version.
